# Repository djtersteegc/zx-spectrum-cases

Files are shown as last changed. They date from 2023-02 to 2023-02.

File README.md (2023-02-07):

After starting to build a couple ZX Spectrum clone boards, I needed to find a case solution.  The reproduction 48K rubber keyboard cases are nice, but a bit rich for my blood and I had also built up a mechanical keyboard using Superfo's Cherry MX compatible PCB that I wanted to use. After seeing  [Lee Smith's Mechtrum on YouTube](https://www.youtube.com/watch?v=O_FdXpOi2W4) that used the same keyboard, I set out to design my own with the following goals:

- Fits on a 220x220 Ender 3 class print bed in one piece
- Easy to print (minimal supports) and optimized for a 0.4mm nozzle and 2mm layer heights
- Minimal filament usage to print quickly and cheaply

Since then Lee has also made STL's of his design available to purchase to print your own for a small fee, so if you have a larger printer and don't mind using a bit more filament (~418 grams) for a slightly beefier design that is another good option now.

## Available Case Models

[ZX 48 Spider](zx-48-spider/README.md)

[Harlequin 48K Rev G](harlequin-48k-rev-g/README.md)

[Harlequin 128 Issue 4A or 4B](harlequin-128-4A-or-4B/README.md)

## The Design

The design is four parts and uses about 185 grams of filament (20% cubic infill) and measures 219 x 136mm at the base.  I've printed mine in PLA. Approximate print times (at 80mm/s, Two Trees SP-5 running Klipper) and filament usage are as follows:

| Component | Time (Hours) | Filament Used (Grams) |
| --- | --- | --- |
| Base | 7.2 | 92 |
| Cover | 1.7 | 21 |
| Keyboard Tray | 3.6 | 46 |
| Keyboard Insert | 1.9 | 26 |

The base holds the PCB and is secured by two (or more) M3x4mm button head screws in the bottom holes. It is designed to sit on four 10mmx2mm rubber feet to elevate the board to the same height as a stock 48K case.  If you have a printer with great parts cooling you can print it without supports, but I print mine with supports on the rear holes to help make them a little cleaner. Each model has a slightly different base since the ports are different and I noticed not all PCB's have the mounting holes in the exact same location.

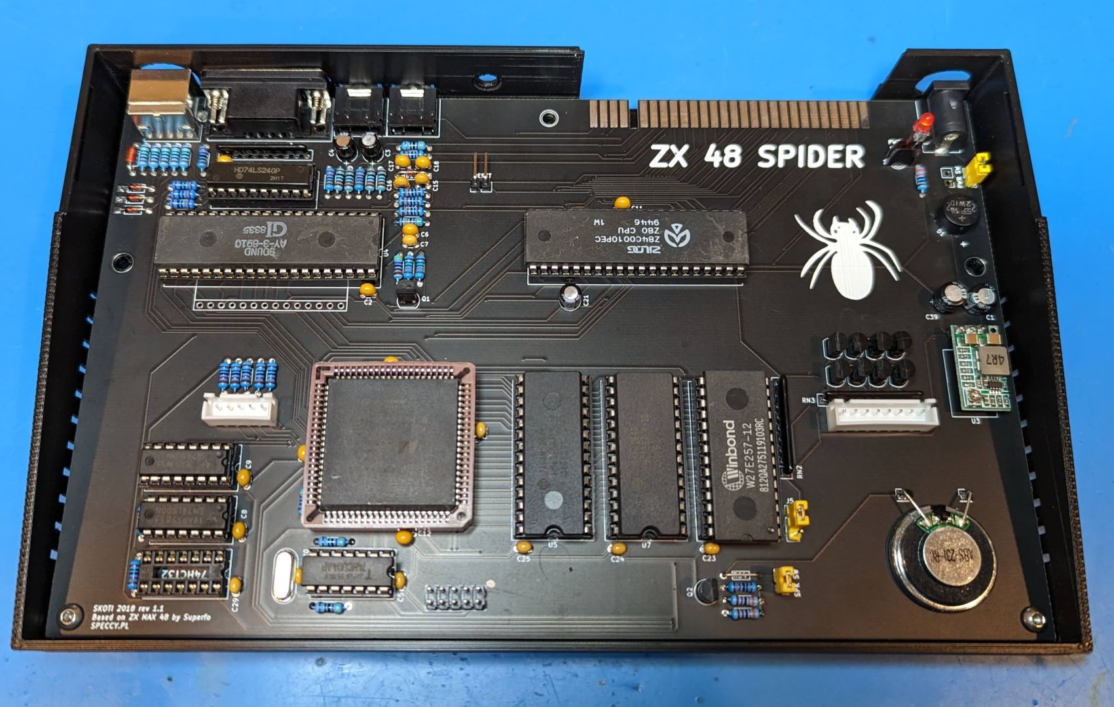
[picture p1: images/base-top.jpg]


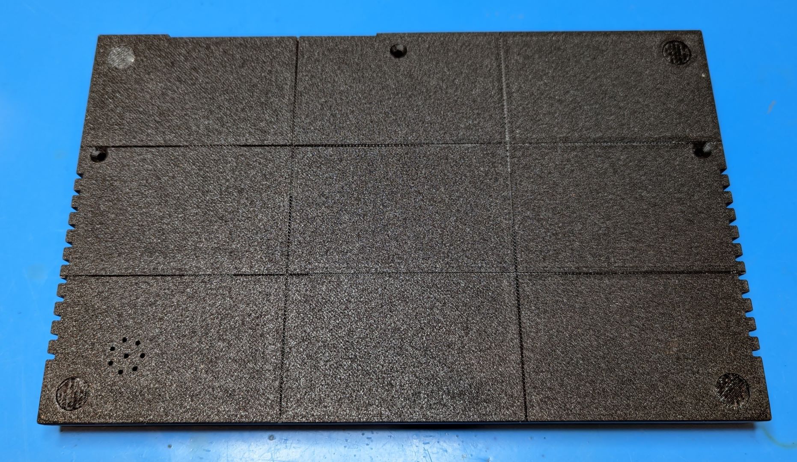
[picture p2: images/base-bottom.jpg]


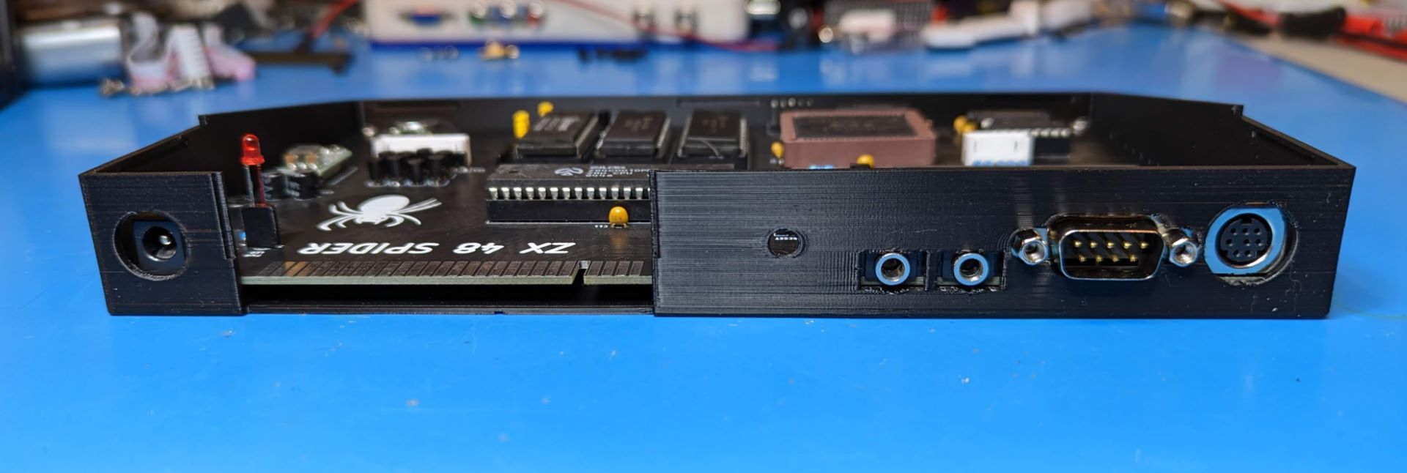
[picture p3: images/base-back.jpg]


The cover is a snapfit design that secures with a M3x10mm taper head scew through the bottom of the case.  The cover is the same dimension across the different model, but has model specific text and in some cases features like a power LED. Print it face down without any supports.

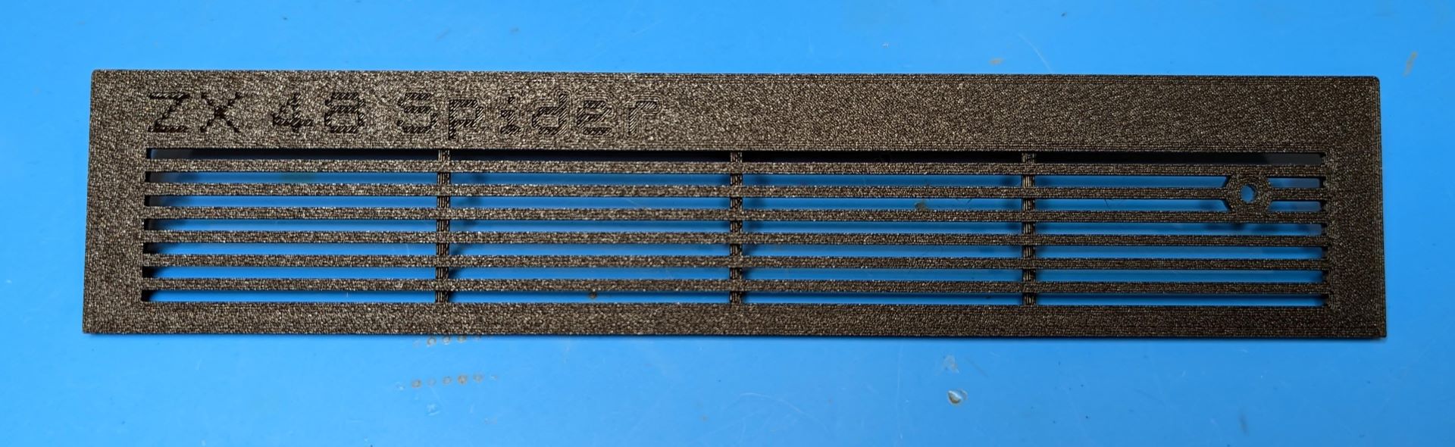
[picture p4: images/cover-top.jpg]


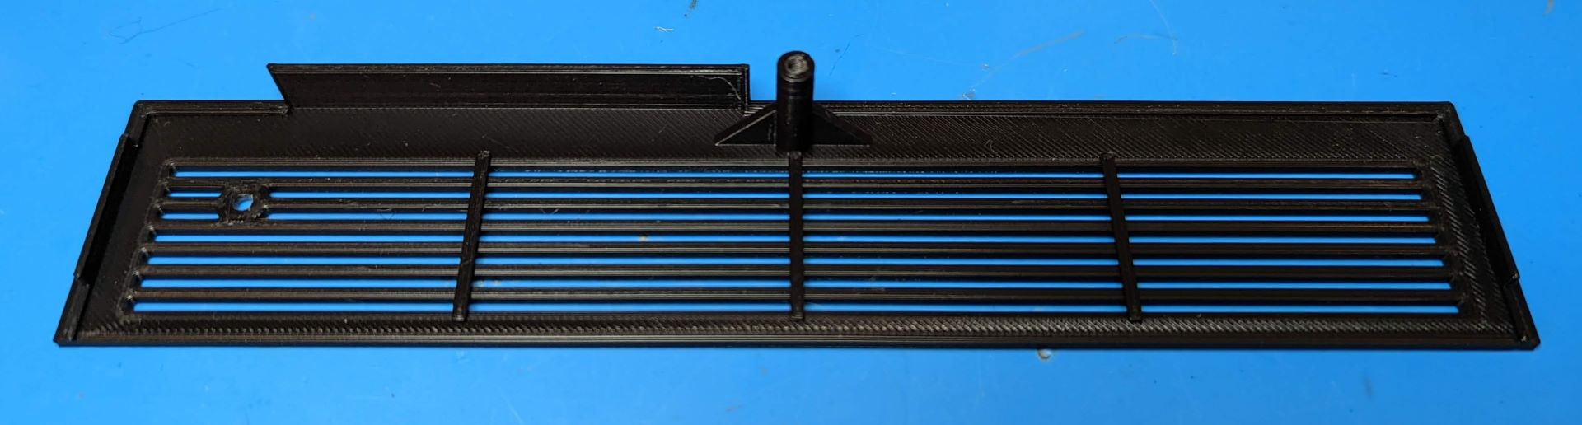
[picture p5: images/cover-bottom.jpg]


The keyboard assembly is two pieces.  The tray should be be printed face down with supports. The insert also prints face down (screw holes facing up) and needs no supports. I experimented with printing both the tray and insert together and only using supports between them where the PCB normally goes, and while it worked and saves about 12g of filament and some printing time, removing the supports is a royal pain so I highly recommend you print them apart.

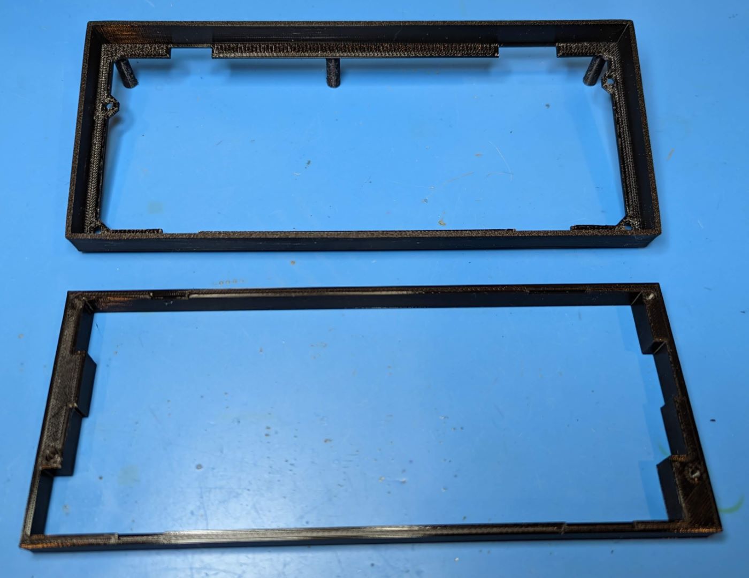
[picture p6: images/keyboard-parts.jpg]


The keyboard PCB is bolted into the keyboard tray and secured by four M3x6mm button head screws to the keyboard insert.  I used 5p and 8p XH2.54 connectors and premade 100mm cables instead of the standard ZX keyboard connectors (TE 5-520315-8 and 5-520315-5) since they are cheap, easy to work with, and don't require an additional adapter or (expensive) 2.54mm solid core ribbon cable for direct insertion.

https://www.aliexpress.us/item/2251832555408405.html

https://www.aliexpress.us/item/2255801038163725.html

Once bolted together, the keyboard assembly snaps to the lower front of the case and is then secured with two M3x10mm taper head scews through the bottom of the case. The center support post rests on the PCB on models where there is room and helps to improve keyboard rigidity a bit.

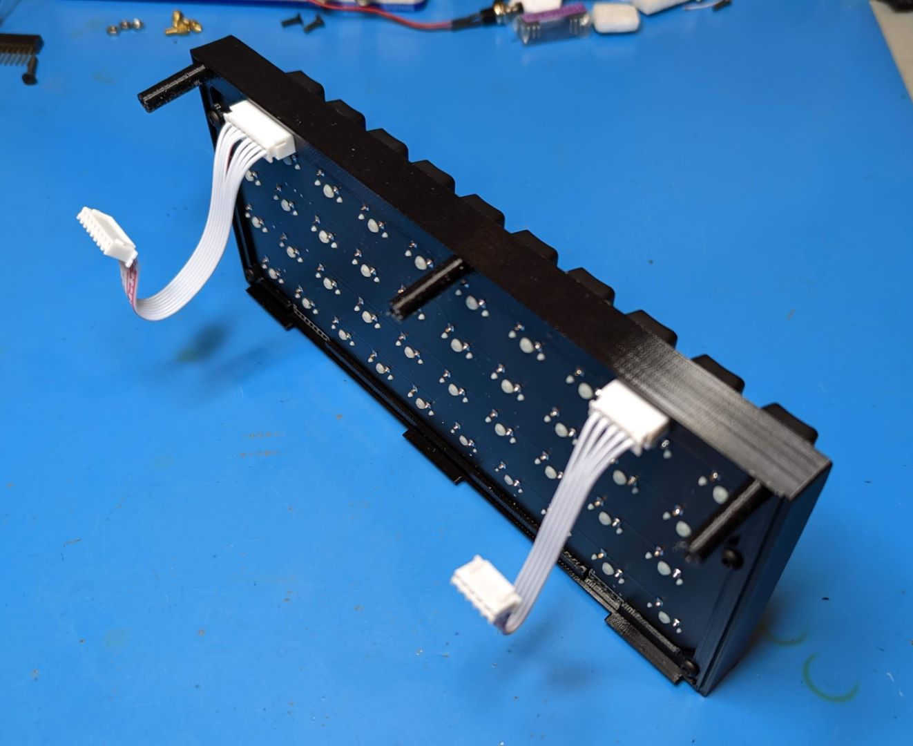
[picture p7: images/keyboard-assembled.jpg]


If you're feeling extra thifty, or just like the look, you can also use the keyboard-tray-minimal files that do not have a bezel or insert, and instead bolts the keyboard to the tray from above with four M3x6 screws and nuts.  This one can be printed face down on the print bed without any supports.

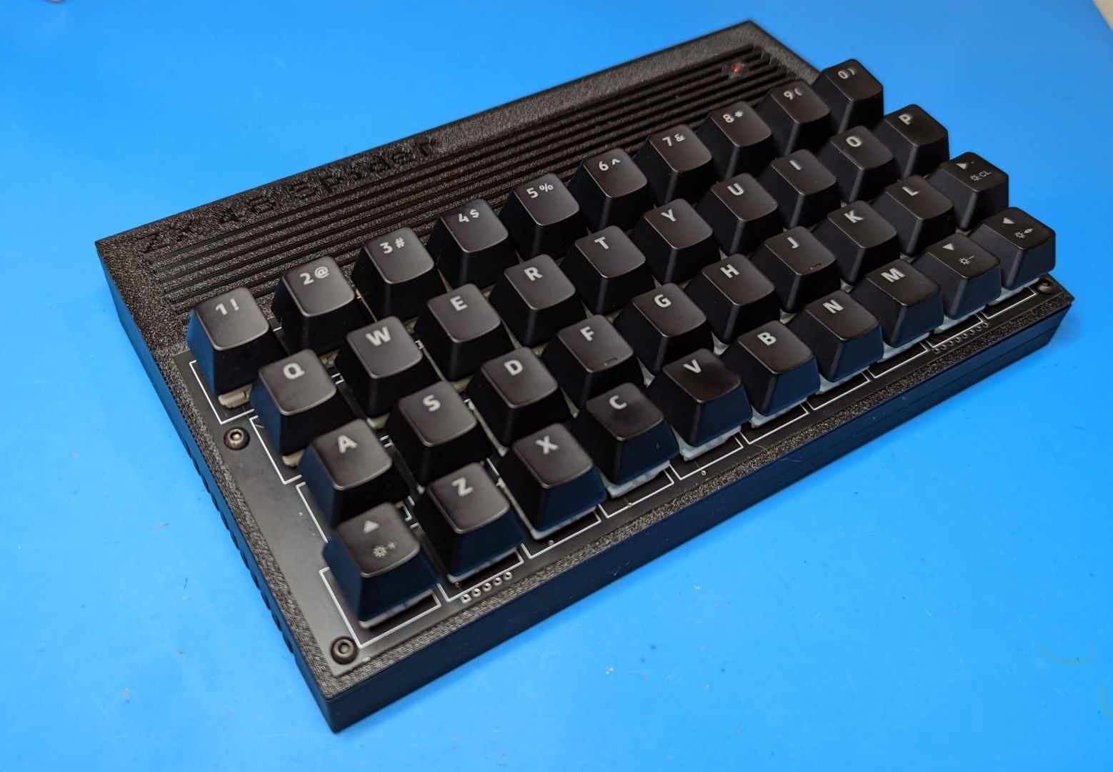
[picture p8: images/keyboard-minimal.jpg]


## The Assembled Case

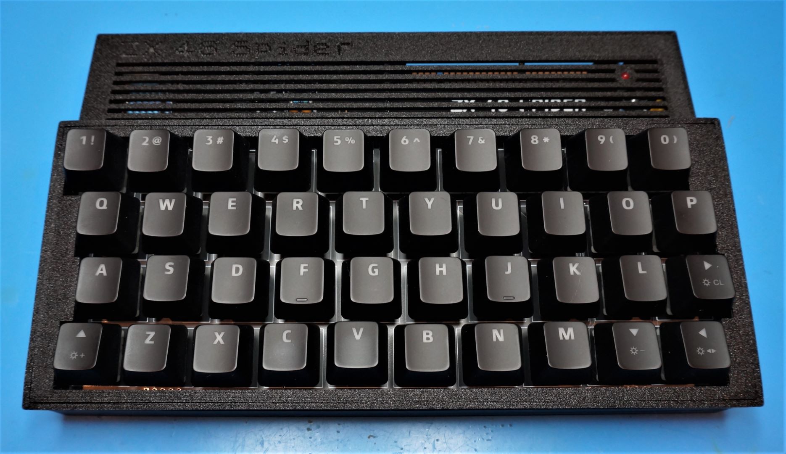
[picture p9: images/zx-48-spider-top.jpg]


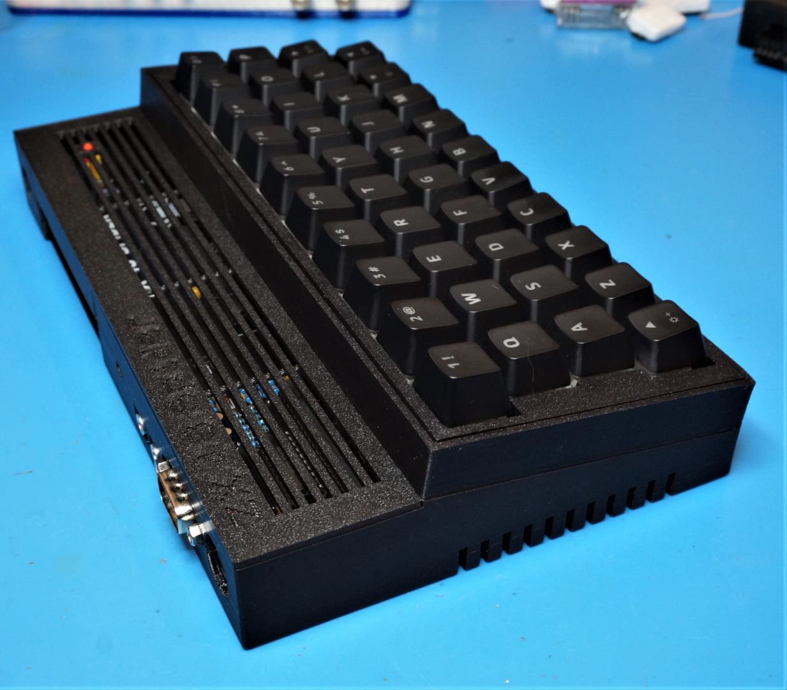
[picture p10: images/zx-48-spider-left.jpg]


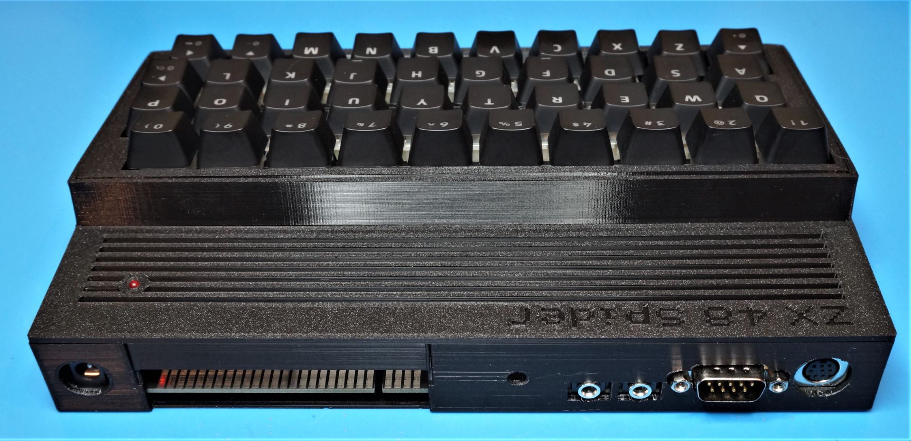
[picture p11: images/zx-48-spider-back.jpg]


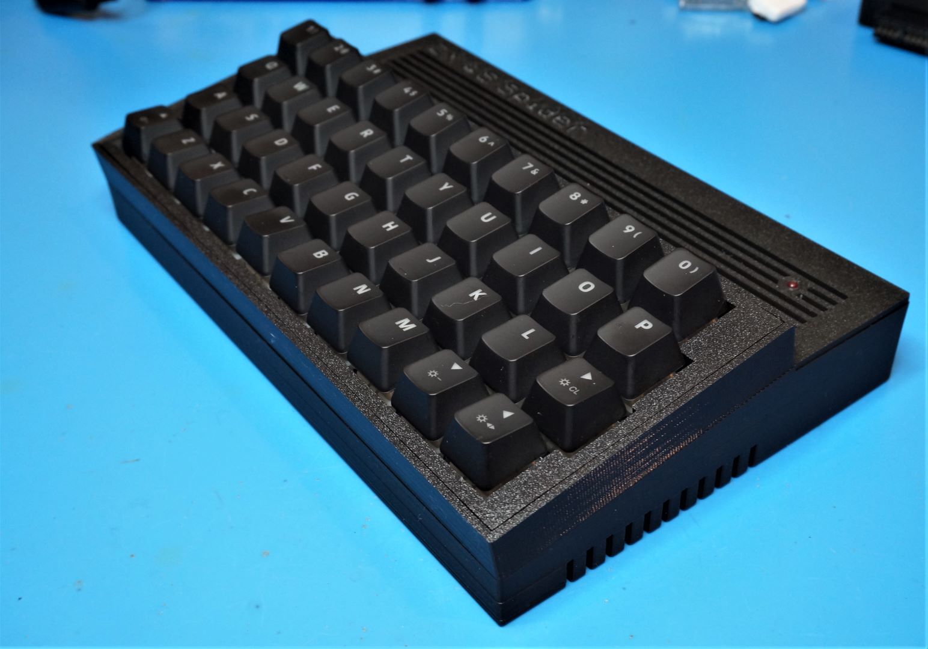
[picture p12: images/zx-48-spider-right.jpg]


## The Keyboard

For all my boards I'm using this PCB that Superfo has shared on PCBWay.  He also has gerbers available for download there if you want to use a cheaper board house like JLCPCB. I would recommend fabbing it with black solder mask.

https://www.pcbway.com/project/shareproject/ZX_Spectrum_Keyboard.html

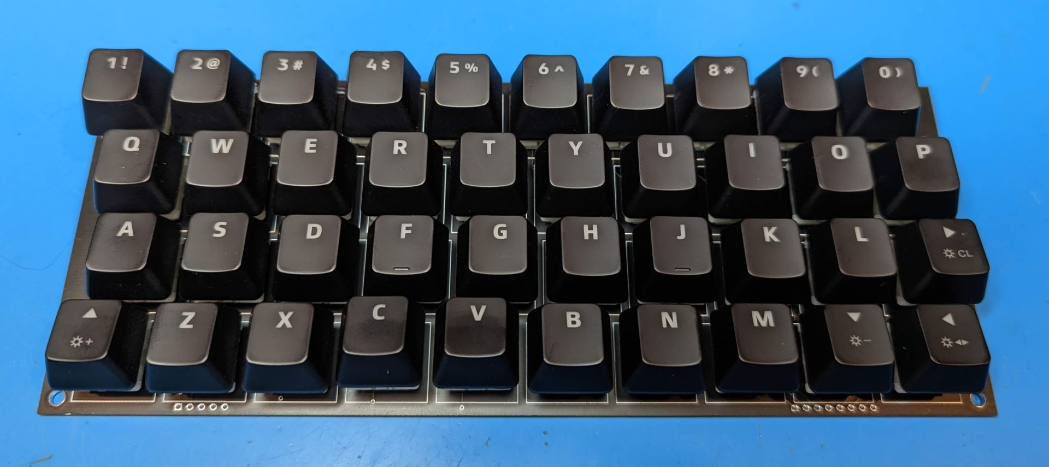
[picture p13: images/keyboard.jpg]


The board is designed to be used with 5 pin PCB mount Cherry MX style switches.  I used Gateron yellows.

https://www.aliexpress.us/item/3256802657968866.html

I also have some cheaper Outemu 3 pin plate mount switches on the way and once they arrive plan on working on a full keyboard tray insert similar to what Lee did with his design for future builds.

https://www.aliexpress.us/item/3256802192387196.html

Currently I just have some random keycaps from a spare keyboard on it, but on the future project list is creating some DIY dye sub PBT DSA profile keycaps using this method

https://www.youtube.com/watch?v=jNZkzK4l0F8

and the graphics file Doug Gabbard had put together for [WASD Keyboards](https://www.wasdkeyboards.com/) (you could also have some printed there for ~$50)

https://github.com/jdgabbard/ZX-Spectrum-MX-Keycaps

## The Design Process

Designing cases by measuring your model with something like some calipers is a pain.  Since most of the boards I was building didn't have full [KiCad](https://www.kicad.org/) or other EDA design files avilable, I had to take the gerbers files, pull them into KiCad GerberViewer and then export a new KiCad PCB file.  From there it was a simple matter of placing footprints and 3D models of key components on the PCB in KiCad and then exporting a STEP file.

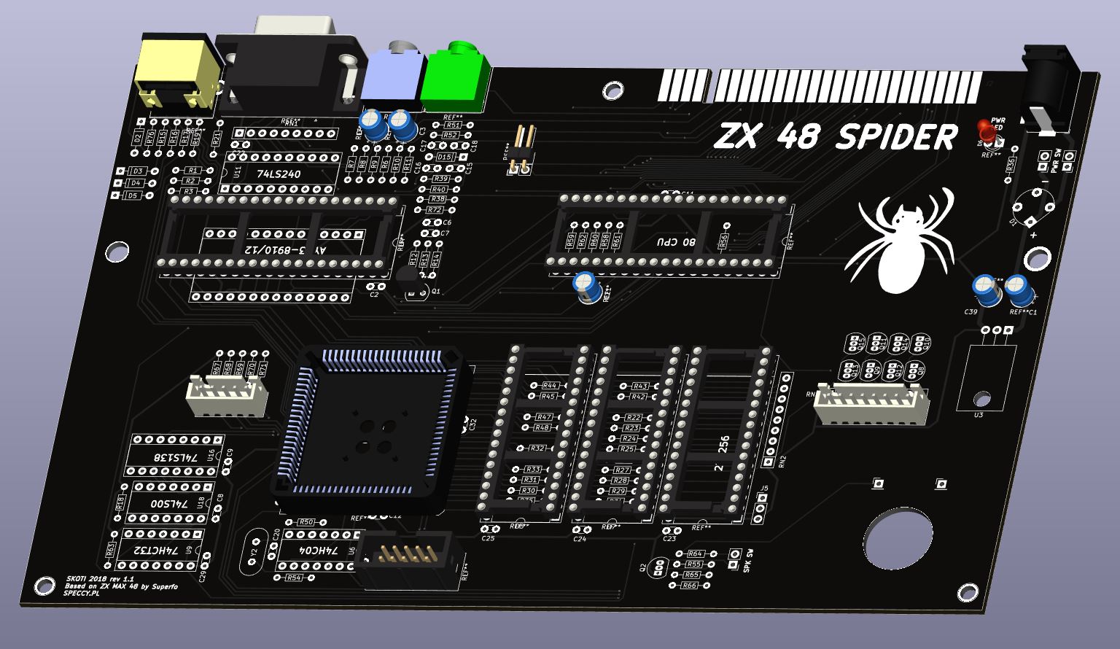
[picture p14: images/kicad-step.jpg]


My current 3D tool of choice is still [Design Spark Mechanical](https://www.rs-online.com/designspark/mechanical-software) (a free, cut down version of Ansys SpaceClaim).  Import the STEP file and then start modeling around it.  Once I had the intial design refined, it's simply a matter of swapping in new STEP files for a different board model, align in to the case walls, and then move the mounting holes and rear ports around as needed. 

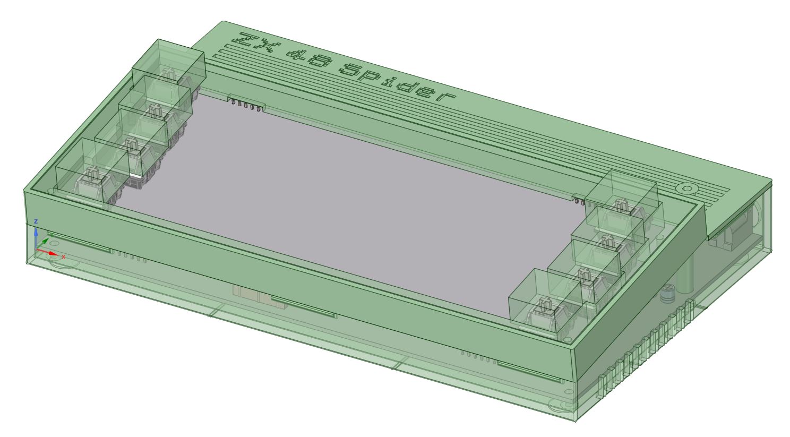
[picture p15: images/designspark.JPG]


I've included the KiCad projects, STEP files, and Designspark design files if anyone wants to modify or improve upon this work.

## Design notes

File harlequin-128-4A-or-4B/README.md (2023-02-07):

This should fit both an issue 4A and issue 4B board. I do not have a copy of this board yet to fully test fit, so this is based on a model I made from the gerbers Don graciously provided. If you do end up printing a copy, would love to hear how it turned out.

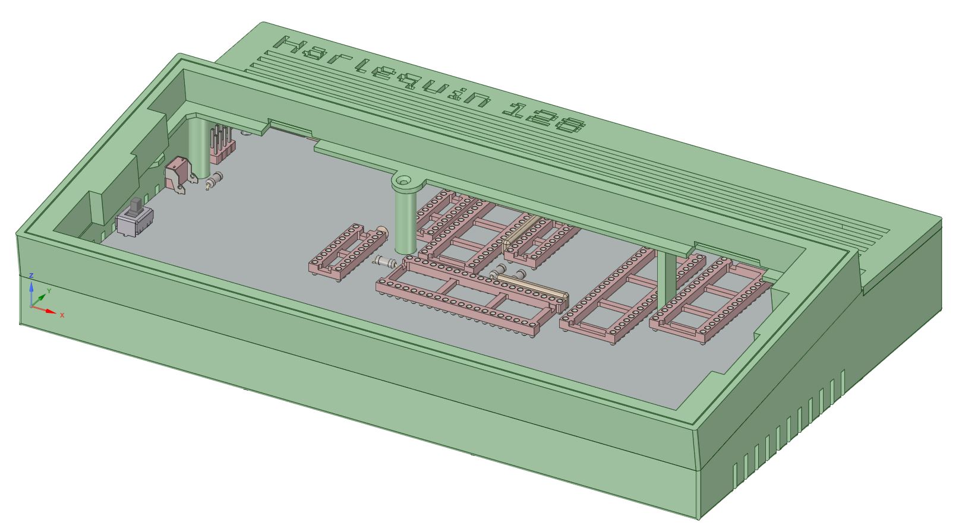
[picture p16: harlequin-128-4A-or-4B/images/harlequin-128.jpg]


Since the board inserts from the back at an angle, you can't use switches that protrude on the left side so the following substituions need to be made with the original BOM.

| Switch | Original | Substitute |
| --- | --- | --- |
| Reset | TE 2-1825027-0 | TE 1825027-2 |
| Timing | E-Switch EG2208 | E-Switch EG2207 |
| NTSC/PAL | Nidec MFS401N-2-Z | None needed, already vertical |

You will need to use a small tool to manipulate the side switches and ROM dipswitches which are also exposed through the top cover.

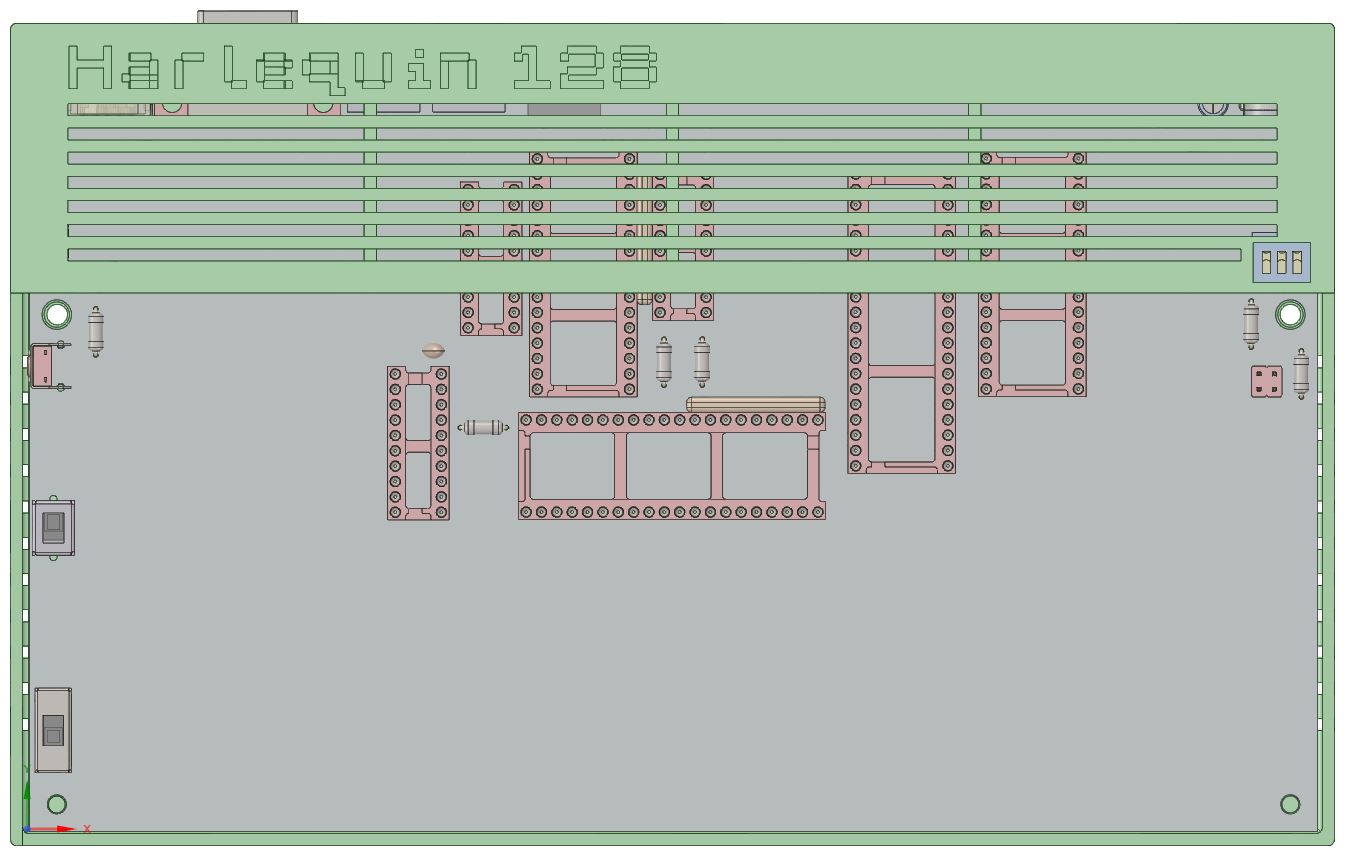
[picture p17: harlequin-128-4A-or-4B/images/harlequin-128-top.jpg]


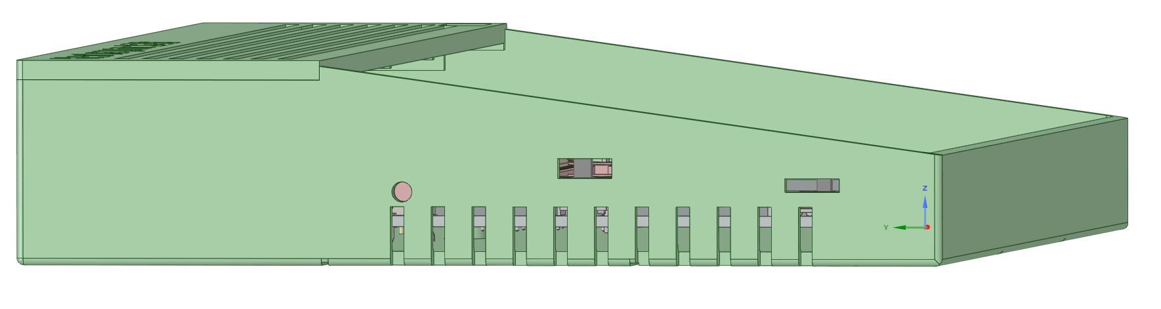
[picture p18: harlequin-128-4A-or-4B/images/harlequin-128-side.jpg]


All ports are exposed on the back.  The audio jack cut out should be large enough to support either the three pin or four pin (with video) options.  The DB9 to DIN-9 spacing is tight so I'm not entirely happy with no wall there, but in my testing with various DIN cables and DSUB jacks on the cases I have built, you pretty much need all that clearance so it is what it is.

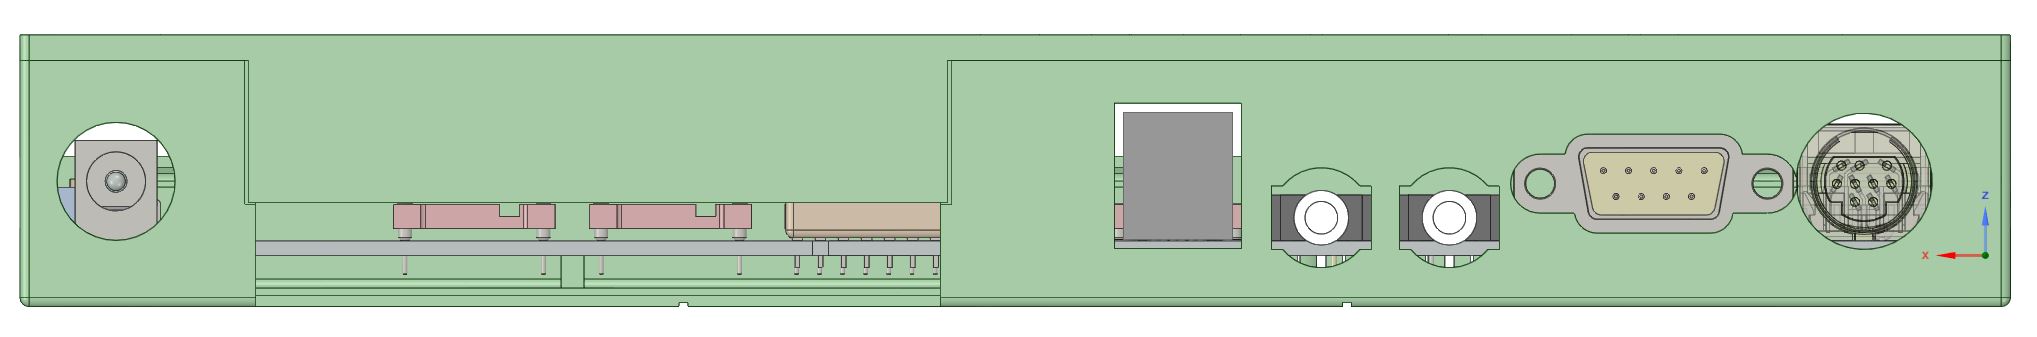
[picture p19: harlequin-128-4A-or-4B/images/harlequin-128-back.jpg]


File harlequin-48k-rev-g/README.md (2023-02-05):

No introduction needed.  I haven't fully built mine yet, but have printed a test copy of the base and everything looks good from a fit up standpoint.

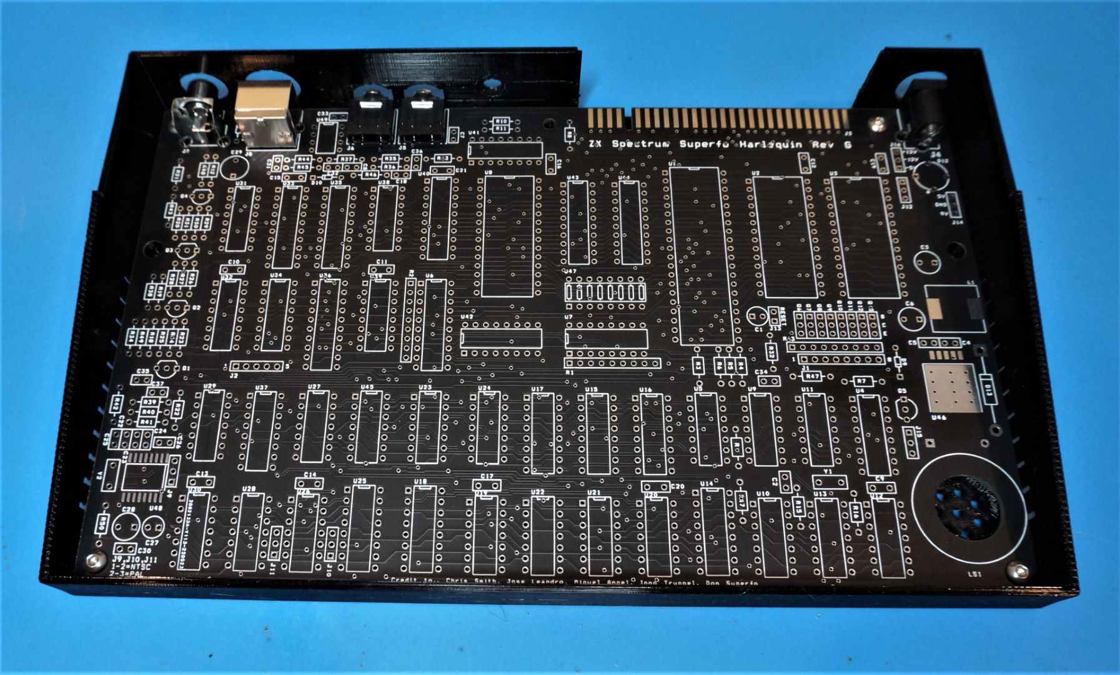
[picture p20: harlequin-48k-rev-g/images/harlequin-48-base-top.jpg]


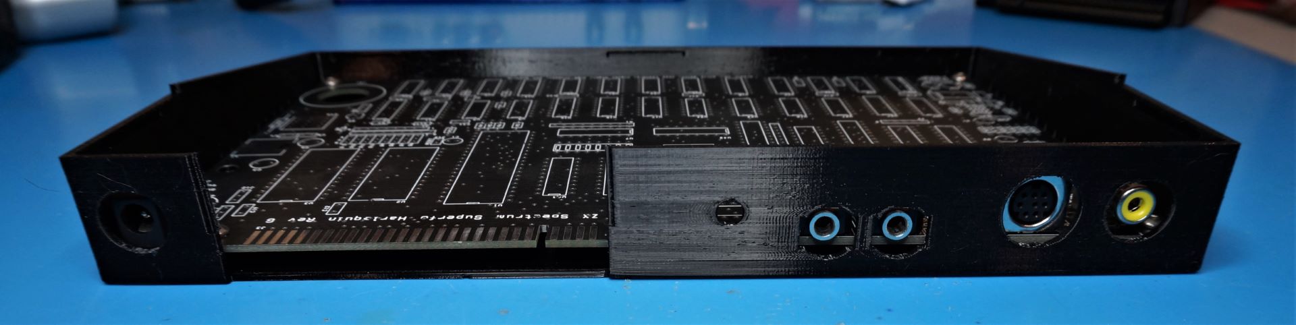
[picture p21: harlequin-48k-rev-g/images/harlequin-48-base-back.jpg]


The rear panel includes a hole to mount a 5mm push button reset switch.

https://www.aliexpress.us/item/2255799950576497.html

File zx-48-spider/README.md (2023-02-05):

Nice clone based on Superfo's ZX Max 48 design available from

https://github.com/konkotgit/ZX-48-Spider



Easy build with support for both AY sound and a Kempston joystick port on board.  Not a lot of info on US boards and groups, but a long discussion thread with the creator on 

https://www.speccy.pl/forum/index.php?topic=5716.0

A standard 3mm LED did not reach through the top of the cover so I mounted it in a 2.54mm 2p female header and cut the legs down a bit until I got the right height.  The red Sharpie on the socket and legs are to mark which leg is postive since they are now both the same length.

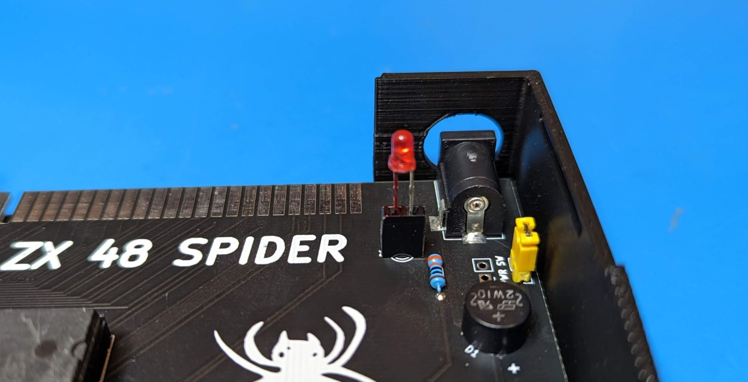
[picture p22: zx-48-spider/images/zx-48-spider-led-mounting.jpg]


The rear panel includes a hole to mount a 5mm push button reset switch.

https://www.aliexpress.us/item/2255799950576497.html

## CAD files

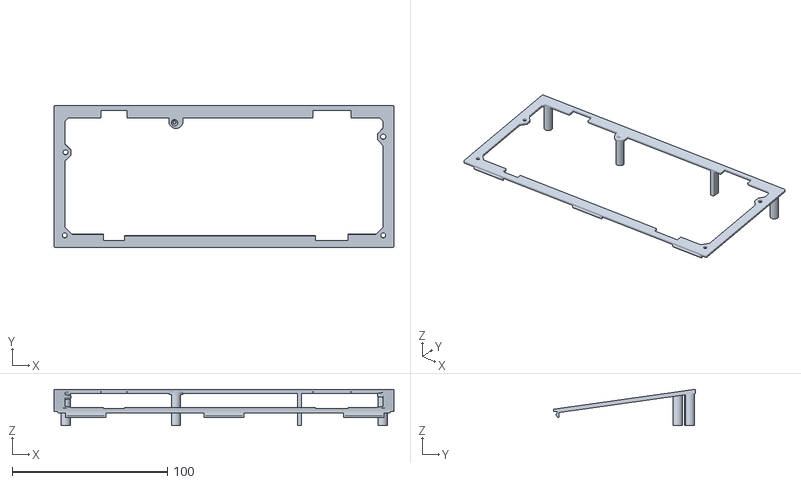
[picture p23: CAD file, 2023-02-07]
harlequin-128-4A-or-4B/STL/harlquin-128-4B-keyboard-tray-minimal.stl
219.0 x 91.6 x 23.4

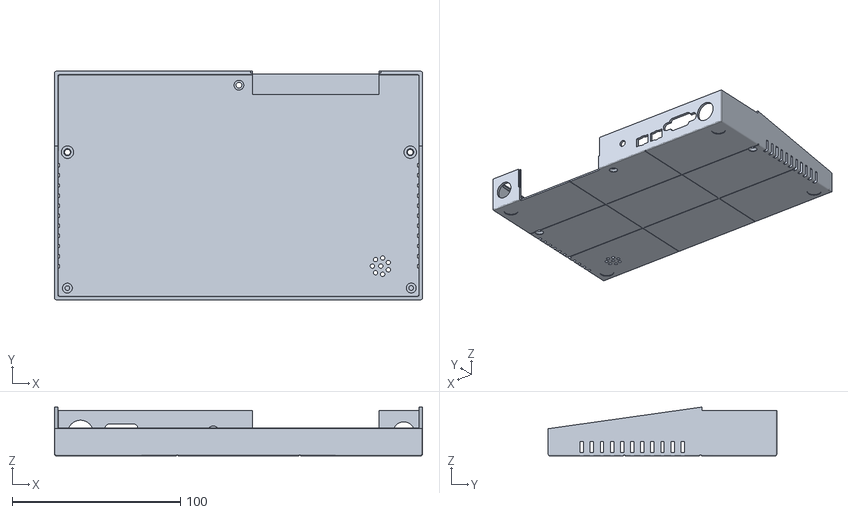
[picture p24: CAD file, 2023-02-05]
zx-48-spider/STL/zx-48-spider-base.stl
219.0 x 136.0 x 29.0

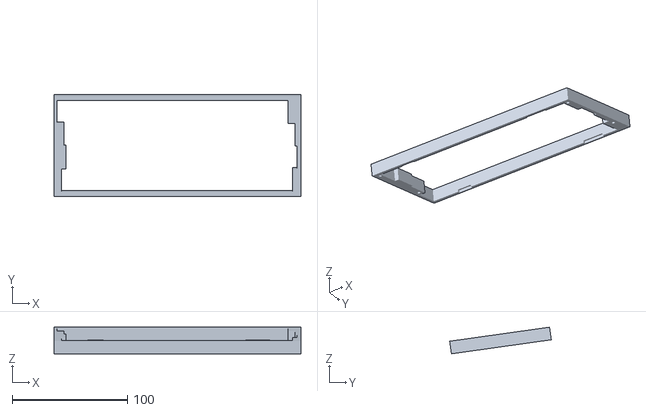
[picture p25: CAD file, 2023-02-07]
harlequin-128-4A-or-4B/STL/harlquin-128-4B-keyboard-insert.stl
214.2 x 88.2 x 23.1

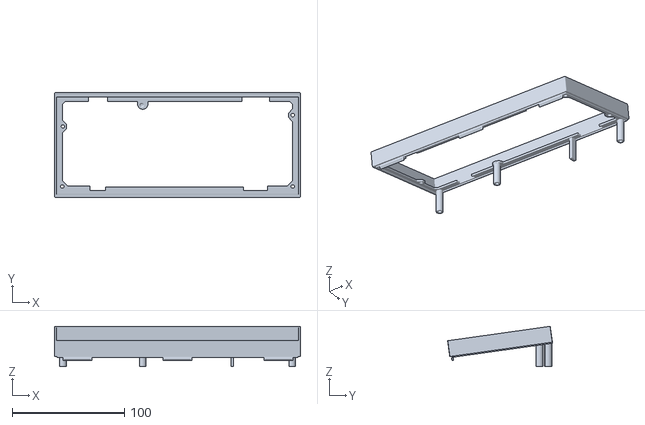
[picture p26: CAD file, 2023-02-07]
harlequin-128-4A-or-4B/STL/harlquin-128-4B-keyboard-tray.stl
219.0 x 93.4 x 35.9

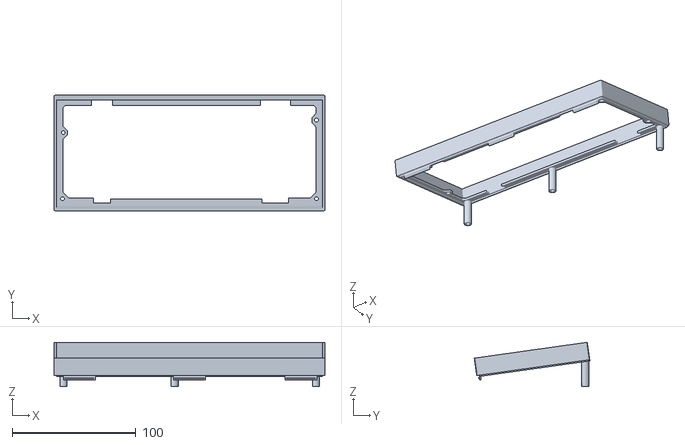
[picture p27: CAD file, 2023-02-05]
zx-48-spider/STL/zx-48-spider-keyboard-tray.stl
219.0 x 93.4 x 35.9

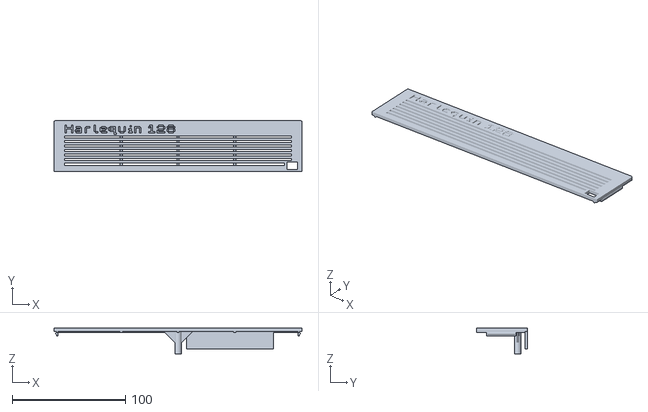
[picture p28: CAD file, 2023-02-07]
harlequin-128-4A-or-4B/STL/harlquin-128-4B-cover.stl
219.0 x 44.6 x 22.7

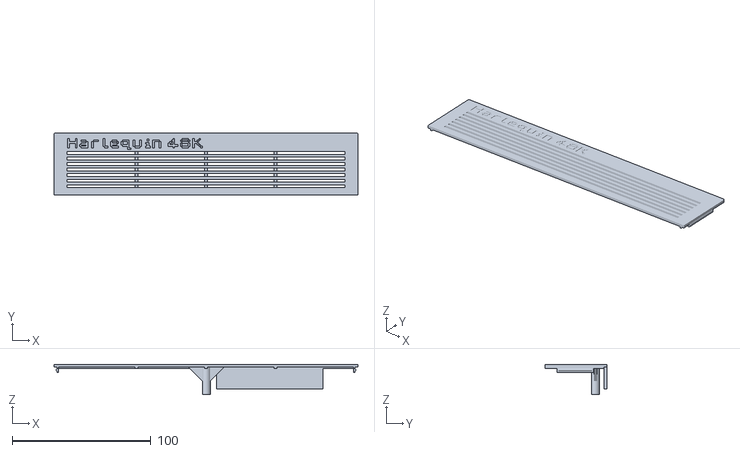
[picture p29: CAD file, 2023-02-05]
harlequin-48k-rev-g/STL/harlequin-48k-cover.stl
219.0 x 44.6 x 21.8

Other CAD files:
harlequin-48k-rev-g/STL/harlequin-48k-keyboard-tray-minimal.stl
harlequin-48k-rev-g/STL/harlequin-48k-keyboard-insert.stl
zx-48-spider/STL/zx-48-spider-keyboard-insert.stl
harlequin-48k-rev-g/STL/harlequin-48k-base.stl
zx-48-spider/STL/zx-48-spider-keyboard-tray-minimal.stl
harlequin-128-4A-or-4B/STL/harlquin-128-4B-base.stl
harlequin-48k-rev-g/STL/harlequin-48k-keyboard-tray.stl
zx-48-spider/STL/zx-48-spider-cover.stl

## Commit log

2023-02-05 Initial commit of ZX 48 Spider case
    [superfo-keyboard.kicad_pcb, zx-48-spider-base.stl, zx-48-spider-cover.stl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]
2023-02-05 Initial Harlequin 48k version
    [harlequin-48k-base.stl, harlequin-48k-cover.stl, harlequin-48k-keyboard-insert.stl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]
2023-02-07 Add more key switches to the top row
    [superfo-keyboard.kicad_pcb]
2023-02-07 Add Harlequin 128 Issue 4A/4B model
    [harlquin-128-4B-base.stl, harlquin-128-4B-cover.stl, harlquin-128-4B-keyboard-insert.stl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]
